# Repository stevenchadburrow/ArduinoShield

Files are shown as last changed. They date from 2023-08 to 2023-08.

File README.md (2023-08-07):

# ArduinoShield

This project is designed to make an Arduino into a standalone microcomputer.

Runs the Arduino Uno at the standard 16 MHz.  The shield gives the ATMega238 microcontroller up to 16KB of additional RAM. VGA output of 512x240 monochrome character display, allowing for 64-column text.  Also supports PS/2 Keyboard input and square wave audio output.

This uses the Xilinx XC9572XL CPLD, programmed using Xilinx ISE and 'xc3sprog'.

BASIC and a Roguelike Game were created for the system.

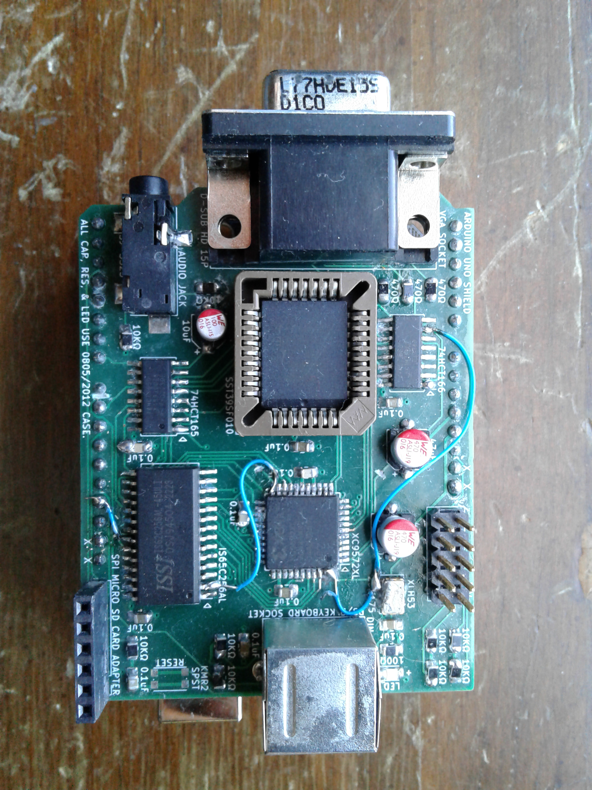
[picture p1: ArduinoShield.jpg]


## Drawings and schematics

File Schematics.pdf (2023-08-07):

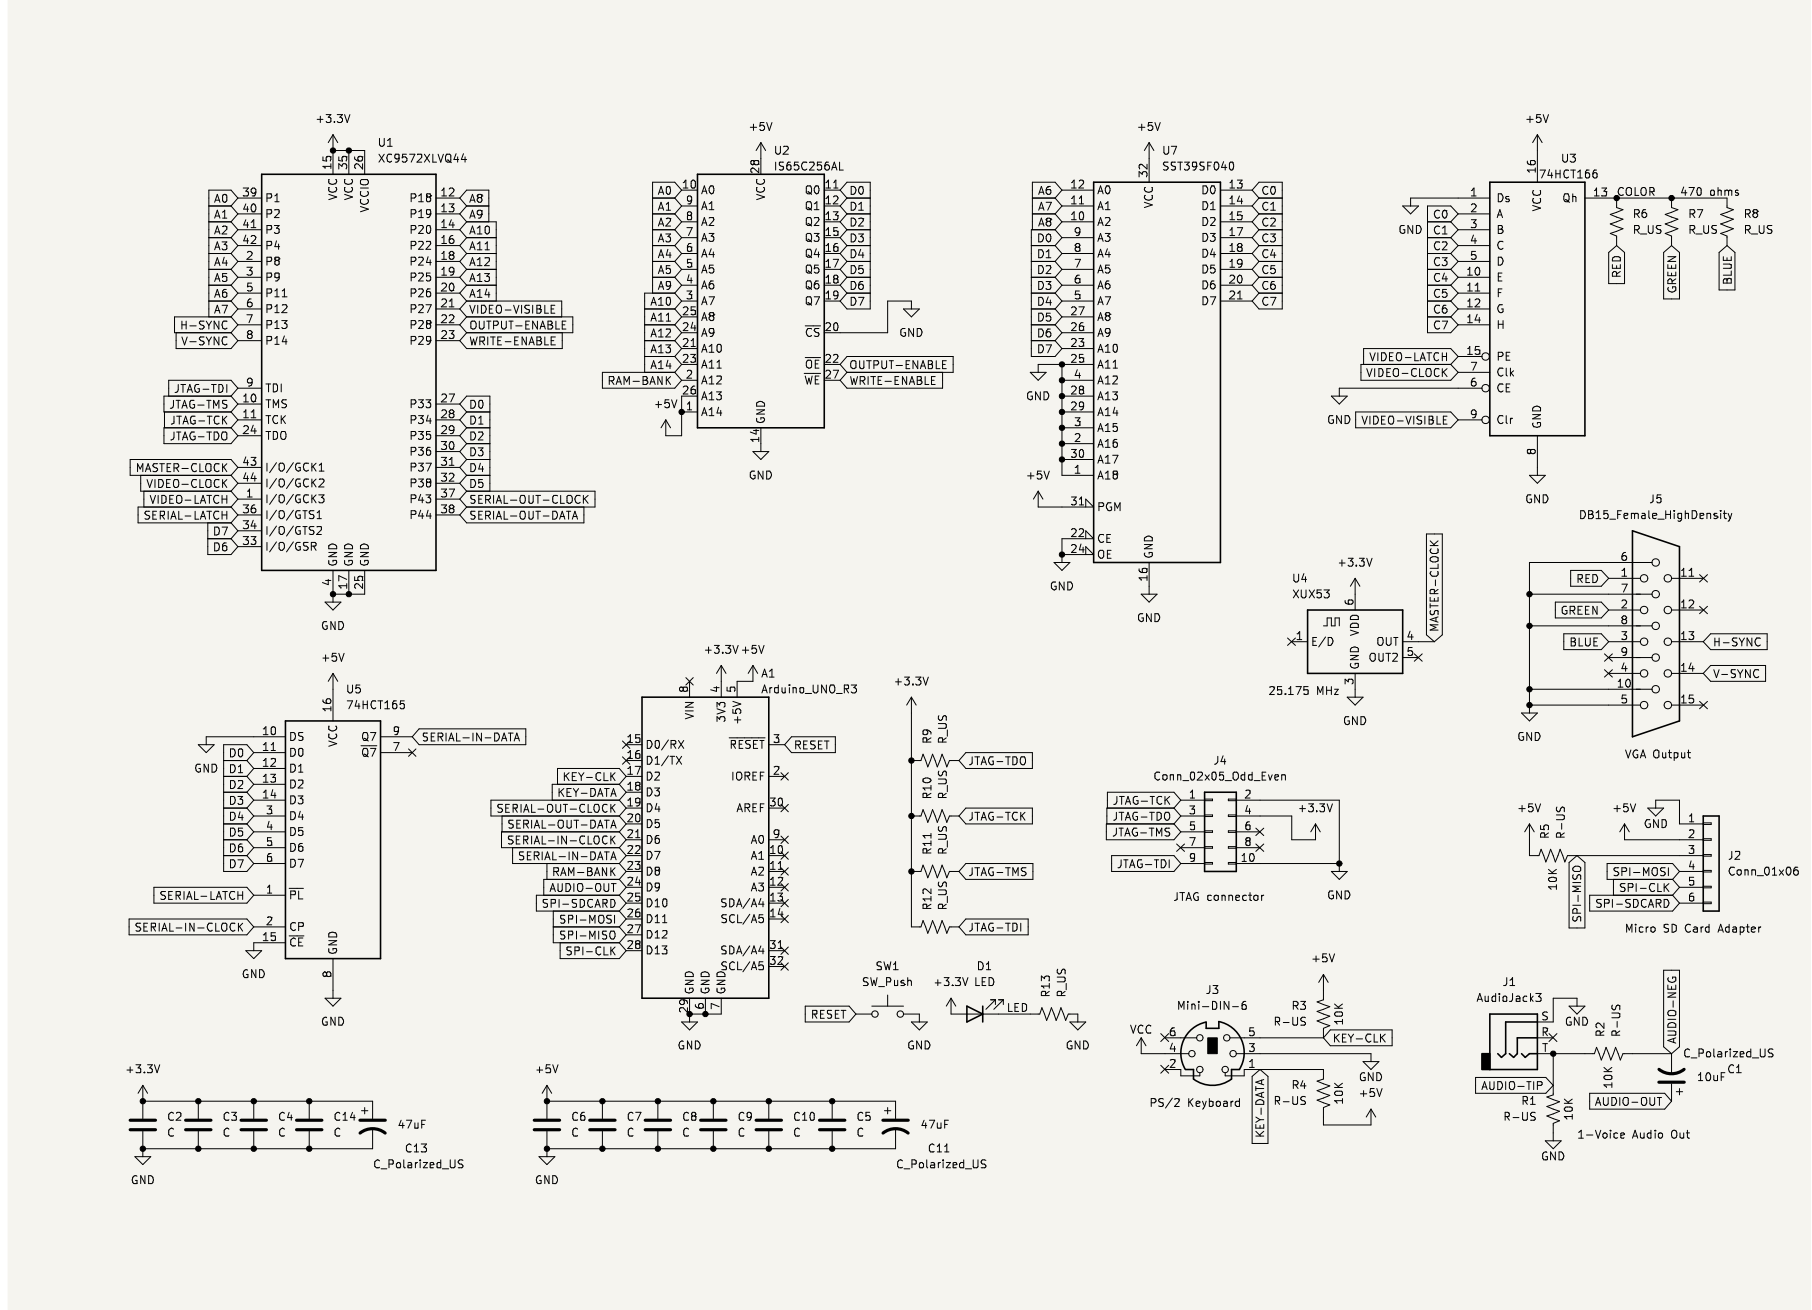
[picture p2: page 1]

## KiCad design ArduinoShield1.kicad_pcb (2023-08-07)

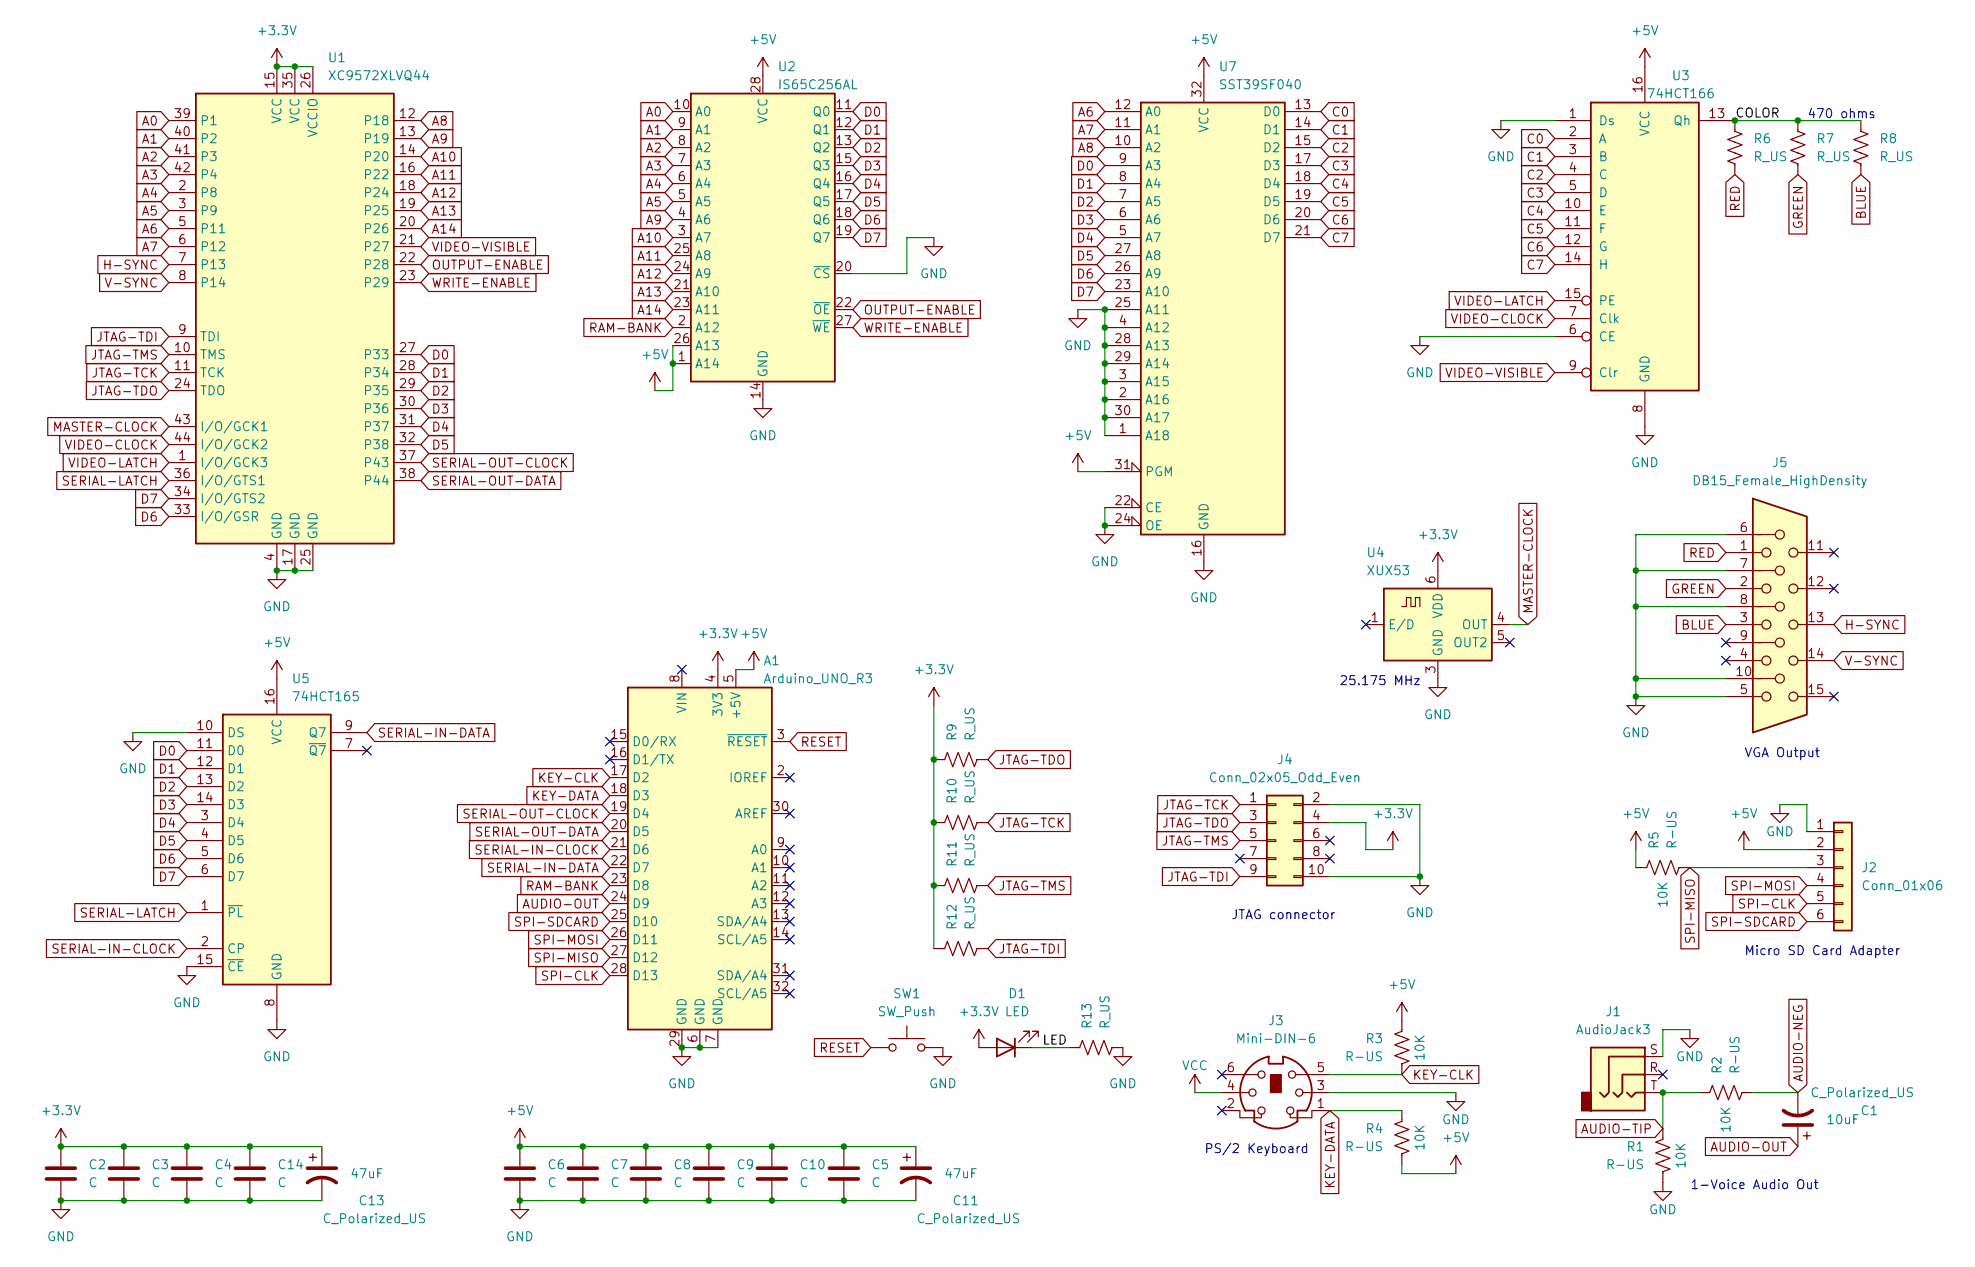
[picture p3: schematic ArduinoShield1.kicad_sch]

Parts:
A1: Arduino_UNO_R3
C1: C_Polarized_US; CP_Elec_4x5.4
C2, C3, C4, C5, C6, C7, C8, C9, C10, C14: C; C_0805_2012Metric_Pad1.18x1.45mm_HandSolder
C11, C13: C_Polarized_US; CP_Elec_5x5.4
D1: LED; LED_1206_3216Metric_Pad1.42x1.75mm_HandSolder
J1: AudioJack3; Jack_3.5mm_CUI_custom_SJ-3524-SMT_Horizontal
J2: Conn_01x06; PinSocket_custompin1_1x06_P2.54mm_Vertical
J3: Mini-DIN-6; PS2_Din6
J4: Conn_02x05_Odd_Even; PinHeader_2x05_P2.54mm_Vertical
J5: DB15_Female_HighDensity; DSUB-15-HD_Female_Horizontal_P2.29x2.54mm_VGA
R1, R2, R3, R4, R5: R-US; R_0805_2012Metric_Pad1.20x1.40mm_HandSolder
R6, R7, R8, R9, R10, R11, R12: R_US; R_0805_2012Metric_Pad1.20x1.40mm_HandSolder
R13: R_US; R_1206_3216Metric_Pad1.30x1.75mm_HandSolder
SW1: SW_Push; SW_Push_1P1T_NO_CK_KMR2
U1: XC9572XLVQ44; TQFP-44_10x10mm_P0.8mm
U2: IS65C256AL; SOIC-28W_custom_7.5x18.7mm_P1.27mm
U3: 74HCT166; SOIC-16_4.55x10.3mm_P1.27mm
U4: XUX53; Oscillator_SMD_IDT_JS6-6_5.0x3.2mm_P1.27mm
U5: 74HCT165; SOIC-16_4.55x10.3mm_P1.27mm
U7: SST39SF040; PLCC-32_THT-Socket

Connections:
+3.3V: A1.4 (3V3), C2.1, C3.1, C4.1, C13.1, C14.1, D1.2 (A), J4.4, R9.1, R10.1, R11.1, R12.1, U1.15 (VCC), U1.26 (VCCIO), U1.35 (VCC), U4.6 (VDD)
/COLOR: R6.1, R7.1, R8.1, U3.13 (Qh)
/LED: D1.1 (K), R13.1
A0: U1.39 (P1), U2.10 (A0)
A1: U1.40 (P2), U2.9 (A1)
A2: U1.41 (P3), U2.8 (A2)
A3: U1.42 (P4), U2.7 (A3)
A4: U1.2 (P8), U2.6 (A4)
A5: U1.3 (P9), U2.5 (A5)
A6: U1.5 (P11), U7.12 (A0)
A7: U1.6 (P12), U7.11 (A1)
A8: U1.12 (P18), U7.10 (A2)
A9: U1.13 (P19), U2.4 (A6)
A10: U1.14 (P20), U2.3 (A7)
A11: U1.16 (P22), U2.25 (A8)
A12: U1.18 (P24), U2.24 (A9)
A13: U1.19 (P25), U2.21 (A10)
A14: U1.20 (P26), U2.23 (A11)
AUDIO-NEG: C1.2, R2.2
AUDIO-OUT: A1.24 (D9), C1.1
AUDIO-TIP: J1.T, R1.1, R2.1
BLUE: J5.3, R8.2
C0: U3.2 (A), U7.13 (D0)
C1: U3.3 (B), U7.14 (D1)
C2: U3.4 (C), U7.15 (D2)
C3: U3.5 (D), U7.17 (D3)
C4: U3.10 (E), U7.18 (D4)
C5: U3.11 (F), U7.19 (D5)
C6: U3.12 (G), U7.20 (D6)
C7: U3.14 (H), U7.21 (D7)
D0: U1.27 (P33), U2.11 (Q0), U5.11 (D0), U7.9 (A3)
D1: U1.28 (P34), U2.12 (Q1), U5.12 (D1), U7.8 (A4)
D2: U1.29 (P35), U2.13 (Q2), U5.13 (D2), U7.7 (A5)
D3: U1.30 (P36), U2.15 (Q3), U5.14 (D3), U7.6 (A6)
D4: U1.31 (P37), U2.16 (Q4), U5.3 (D4), U7.5 (A7)
D5: U1.32 (P38), U2.17 (Q5), U5.4 (D5), U7.27 (A8)
D6: U1.33 (I/O/GSR), U2.18 (Q6), U5.5 (D6), U7.26 (A9)
D7: U1.34 (I/O/GTS2), U2.19 (Q7), U5.6 (D7), U7.23 (A10)
GND: A1.6 (GND), A1.7 (GND), A1.29 (GND), C2.2, C3.2, C4.2, C5.2, C6.2, C7.2, C8.2, C9.2, C10.2, C11.2, C13.2, C14.2, J1.S, J2.1, J3.3, J4.2, J4.10, J5.5, J5.6, J5.7, J5.8, J5.10, R1.2, R13.2, SW1.2, U1.4 (GND), U1.17 (GND), U1.25 (GND), U2.14 (GND), U2.20 (~CS), U3.1 (Ds), U3.6 (CE), U3.8 (GND), U4.3 (GND), U5.8 (GND), U5.10 (DS), U5.15 (~CE), U7.1 (A18), U7.2 (A16), U7.3 (A15), U7.4 (A12), U7.16 (GND), U7.22 (CE), U7.24 (OE), U7.25 (A11), U7.28 (A13), U7.29 (A14), U7.30 (A17)
GREEN: J5.2, R7.2
H-SYNC: J5.13, U1.7 (P13)
JTAG-TCK: J4.1, R10.2, U1.11 (TCK)
JTAG-TDI: J4.9, R12.2, U1.9 (TDI)
JTAG-TDO: J4.3, R9.2, U1.24 (TDO)
JTAG-TMS: J4.5, R11.2, U1.10 (TMS)
KEY-CLK: A1.17 (D2), J3.5, R3.2
KEY-DATA: A1.18 (D3), J3.1, R4.1
MASTER-CLOCK: U1.43 (I/O/GCK1), U4.4 (OUT)
OUTPUT-ENABLE: U1.22 (P28), U2.22 (~OE)
RAM-BANK: A1.23 (D8), U2.2 (A12)
RED: J5.1, R6.2
RESET: A1.3 (~RESET), SW1.1
SERIAL-IN-CLOCK: A1.21 (D6), U5.2 (CP)
SERIAL-IN-DATA: A1.22 (D7), U5.9 (Q7)
SERIAL-LATCH: U1.36 (I/O/GTS1), U5.1 (~PL)
SERIAL-OUT-CLOCK: A1.19 (D4), U1.37 (P43)
SERIAL-OUT-DATA: A1.20 (D5), U1.38 (P44)
SPI-CLK: A1.28 (D13), J2.5
SPI-MISO: A1.27 (D12), J2.3, R5.2
SPI-MOSI: A1.26 (D11), J2.4
SPI-SDCARD: A1.25 (D10), J2.6
V-SYNC: J5.14, U1.8 (P14)
VIDEO-CLOCK: U1.44 (I/O/GCK2), U3.7 (Clk)
VIDEO-LATCH: U1.1 (I/O/GCK3), U3.15 (PE)
VIDEO-VISIBLE: U1.21 (P27), U3.9 (Clr)
WRITE-ENABLE: U1.23 (P29), U2.27 (~WE)

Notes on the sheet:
PS/2 Keyboard
JTAG connector
1-Voice Audio Out
Micro SD Card Adapter
VGA Output
25.175 MHz
470 ohms

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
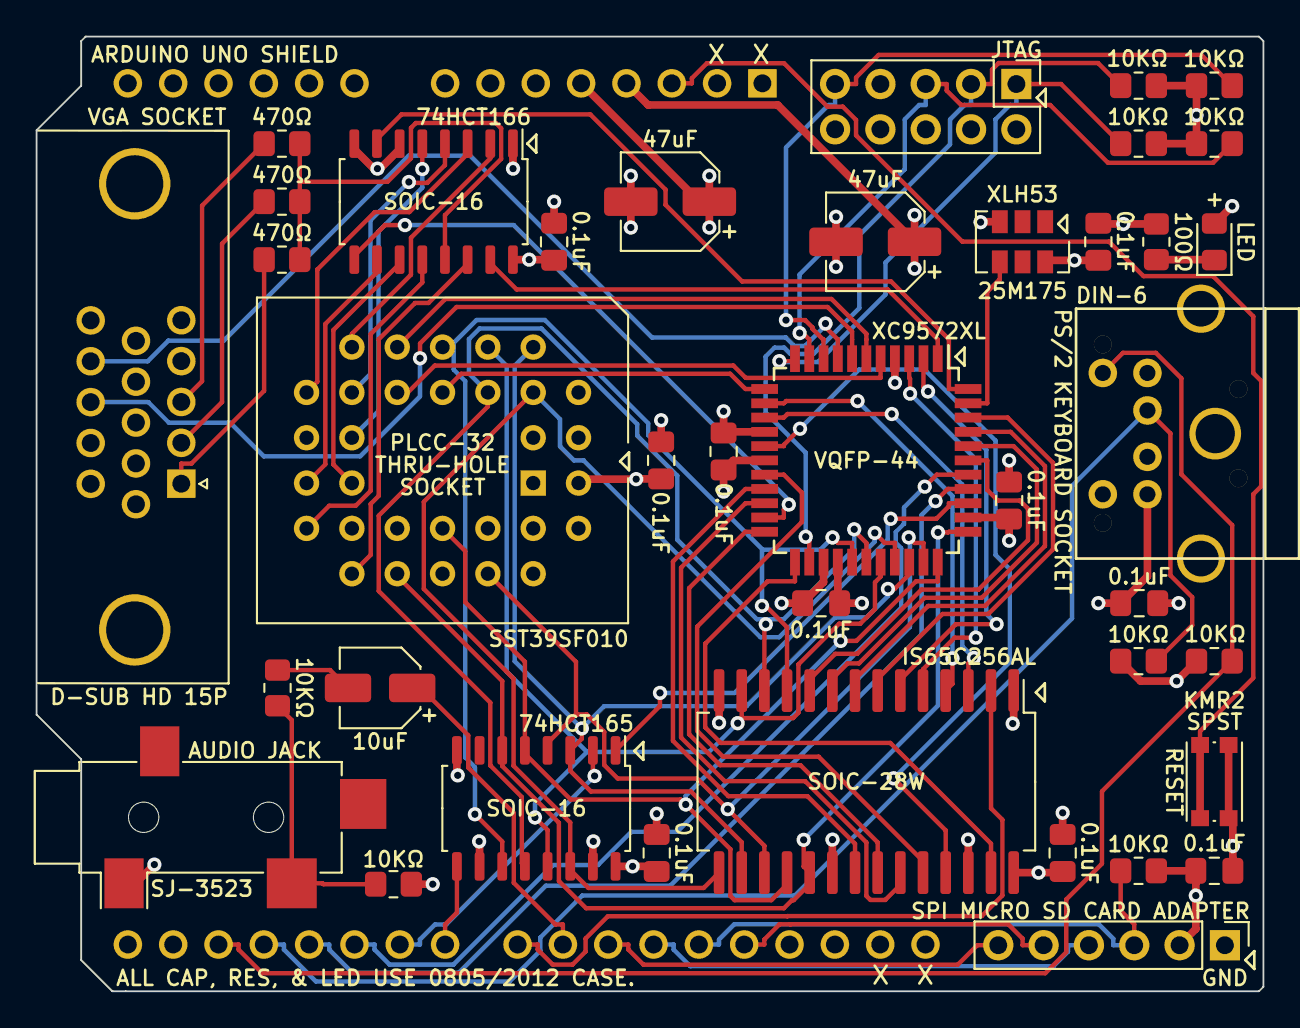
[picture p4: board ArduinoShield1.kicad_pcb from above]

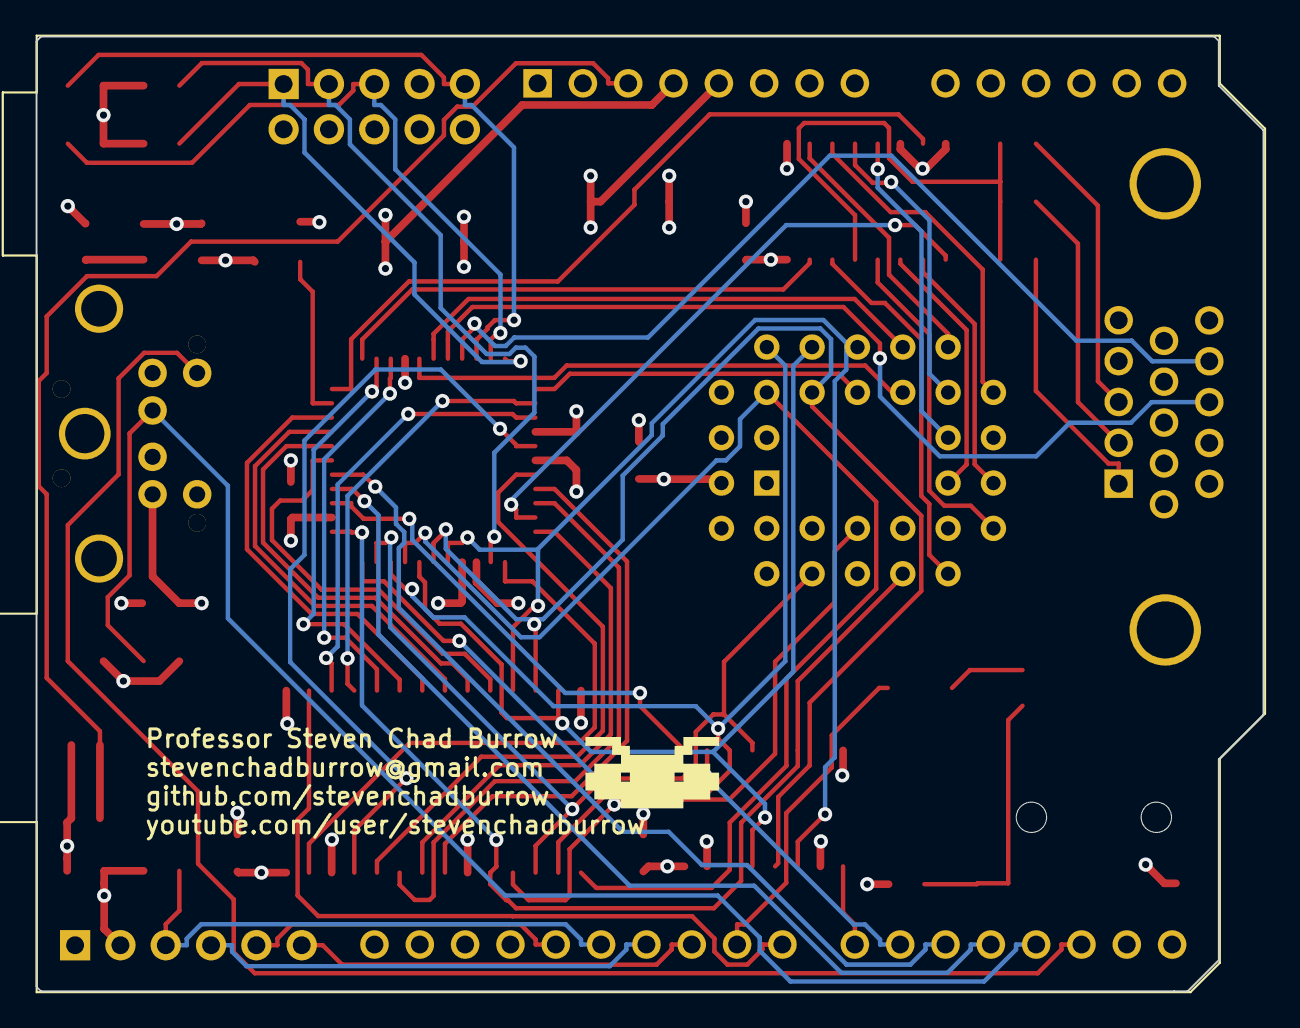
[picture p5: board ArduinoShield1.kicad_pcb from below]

Board: 4 copper layers, 68.8 x 53.5 mm, 41 parts (2 on the bottom side), 67 nets.

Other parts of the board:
G100: LOGO; Mystery

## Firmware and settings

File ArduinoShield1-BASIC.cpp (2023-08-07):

// This is written for the Arduino UNO
// To run this, you can either use the Arduino IDE AppImage,
// OR you can use 'arduino-cli'.
// Follow typical installation process for the 'arduino-cli'.
// The following bash script can be used to automatically program the Arduino UNO:

// echo "ArduinoProgrammer.sh <sketch_file>"
// x=${1%.*}
// y=${x##*/}
// /path/to/arduino-cli sketch new $x
// cp $1 $x/$y.ino
// /path/to/arduino-cli compile --fqbn arduino:avr:uno $x/$y.ino
// /path/to/arduino-cli upload -p /dev/ttyACM0 --fqbn arduino:avr:uno $x/$y.ino
// /path/to/arduino-cli monitor -p /dev/ttyACM0

// You can put that script into a .sh file to let it program automatically.
// No extra libraries should be needed to be installed here,
// the <EEPROM.h> library should be built in and does not need to be installed separately.


#include <EEPROM.h>

unsigned char shared_memory[512]; // duplicated in first 4K from $0000-$0FFF
unsigned char screen_memory[960]; // used for 40x24 and 64x15 fast vertical scrolling (and rogue variables too...)

const bool serial_debug = false; // change to stop error messages
const bool serial_output = true; // change to stop serial output
const bool serial_input = true; // change to stop serial input
unsigned char serial_last = 0x00;

int display_width = 40; // 40 or 64
int display_height = 24; // 24 or 15
int display_left = 12; // 12 or 0
int display_top = 1; // 1 or 5

const bool display_check = false; // double checks reads and writes
const int display_delay = 1; // microseconds

const int display_input_clock = 6;
const int display_input_data = 7;

const int display_output_clock = 4;
const int display_output_data = 5;

//const int display_ram_bank = 8; // not used anymore
//int display_ram_bank_value = 0;

void display_toggleinput()
{
	digitalWrite(display_input_clock, HIGH);
	digitalWrite(display_input_clock, LOW);
};

void display_toggleoutput()
{
	digitalWrite(display_output_clock, HIGH);
	digitalWrite(display_output_clock, LOW);
};

unsigned char display_receivebyte()
{
	unsigned char temp_value = 0x00;

	for (int i=0; i<8; i++)
	{
		temp_value = temp_value << 1;

		if (digitalRead(display_input_data) == HIGH)
		{
			temp_value += 0x01;
		}

		display_toggleinput();
	}
	
	return temp_value;
};

void display_sendbyte(const unsigned char value)
{
	unsigned char temp_value = value;

	for (int i=0; i<8; i++)
	{
		if (temp_value >= 0x80)
		{
			digitalWrite(display_output_data, HIGH);
		}
		else
		{
			digitalWrite(display_output_data, LOW);
		}

		temp_value = temp_value << 1;

		display_toggleoutput();
	}
};

unsigned char display_receivepacket(const unsigned char high, const unsigned char low) // double check each byte received
{
	if (display_check)
	{
		display_sendbyte((unsigned char)((high&0x3F)+0x80));
		display_sendbyte((unsigned char)(low));
		display_sendbyte((unsigned char)(0x00));
		delayMicroseconds(display_delay); // just in case
		display_toggleoutput();

		unsigned char temp_check[2];

		temp_check[1] = temp_check[0];

		temp_check[0] = display_receivebyte(); 

		do
		{
			display_sendbyte((unsigned char)((high&0x3F)+0x80));
			display_sendbyte((unsigned char)(low));
			display_sendbyte((unsigned char)(0x00));
			delayMicroseconds(display_delay); // just in case
			display_toggleoutput();
	
			temp_check[1] = temp_check[0];
	
			temp_check[0] = display_receivebyte();
	
			if (serial_debug)
			{
				if (temp_check[0] != temp_check[1])
				{
					unsigned char temp_binary;
	
					Serial.println("");
	
					Serial.print('R');
					Serial.print(' ');
					
					temp_binary = temp_check[0];
	
					for (int i=0; i<8; i++)
					{
						if (temp_binary >= 0x80) Serial.print('1');
						else Serial.print('0');
					
						temp_binary = temp_binary << 1;
		
						if (i == 3) Serial.print(' ');
					}
					
					Serial.println("");
	
					Serial.print(' ');
					Serial.print(' ');
	
					temp_binary = temp_check[1];
	
					for (int i=0; i<8; i++)
					{
						if (temp_binary >= 0x80) Serial.print('1');
						else Serial.print('0');
					
						temp_binary = temp_binary << 1;
	
						if (i == 3) Serial.print(' ');
					}
	
					Serial.println("");
				}
			}
		} 
		while (temp_check[0] != temp_check[1]);

		return temp_check[0];
	}
	else
	{
		display_sendbyte((unsigned char)((high&0x3F)+0x80));
		display_sendbyte((unsigned char)(low));
		display_sendbyte((unsigned char)(0x00));
		delayMicroseconds(display_delay); // just in case
		display_toggleoutput();	
	
		return display_receivebyte();
	}
};

void display_sendpacket(const unsigned char high, const unsigned char low, const unsigned char value) // only check bytes NOT sent to screen
{
	if (display_check)
	{
		unsigned char temp_check;

		do
		{
			display_sendbyte((unsigned char)((high&0x3F)+0xC0));
			display_sendbyte((unsigned char)(low));
			display_sendbyte((unsigned char)(value));
			delayMicroseconds(display_delay); // just in case
			display_toggleoutput();
	
			if ((unsigned char)(high&0x08) == 0x08)
			{
				display_sendbyte((unsigned char)((high&0x3F)+0x80));
				display_sendbyte((unsigned char)(low));
				display_sendbyte((unsigned char)(value));
				delayMicroseconds(display_delay); // just in case
				display_toggleoutput();
	
				temp_check = display_receivebyte();
			}
			else
			{
				temp_check = value;
			}
	
			if (serial_debug)
			{
				if (temp_check != value)
				{
					unsigned char temp_binary;
	
					Serial.println("");
	
					Serial.print('W');
					Serial.print(' ');
					
					temp_binary = temp_check;
	
					for (int i=0; i<8; i++)
					{
						if (temp_binary >= 0x80) Serial.print('1');
						else Serial.print('0');
					
						temp_binary = temp_binary << 1;
		
						if (i == 3) Serial.print(' ');
					}
					
					Serial.println("");
	
					Serial.print(' ');
					Serial.print(' ');
	
					temp_binary = value;
	
					for (int i=0; i<8; i++)
					{
						if (temp_binary >= 0x80) Serial.print('1');
						else Serial.print('0');
					
						temp_binary = temp_binary << 1;
	
						if (i == 3) Serial.print(' ');
					}
	
					Serial.println("");
				}
			}
		}
		while (temp_check != value);
	}
	else
	{
		display_sendbyte((unsigned char)((high&0x3F)+0xC0));
		display_sendbyte((unsigned char)(low));
		display_sendbyte((unsigned char)(value));
		delayMicroseconds(display_delay); // just in case
		display_toggleoutput();
	}
};

unsigned char display_receivecharacter(const unsigned char row, const unsigned char column)
{
	unsigned char low = (unsigned char)((unsigned char)(column & 0x3F) + (unsigned char)((row & 0x03) << 6));
	unsigned char high = (unsigned char)((row & 0xFC) >> 2);

	return display_receivepacket(high, low);
};

void display_sendcharacter(const unsigned char row, const unsigned char column, const unsigned char value)
{
	unsigned char low = (unsigned char)((unsigned char)(column & 0x3F) + (unsigned char)((row & 0x03) << 6));
	unsigned char high = (unsigned char)((row & 0xFC) >> 2);

	display_sendpacket(high, low, value);
};

void display_initialize()
{
	pinMode(display_output_clock, OUTPUT);
	pinMode(display_output_data, OUTPUT);

	digitalWrite(display_output_clock, LOW);
	digitalWrite(display_output_data, LOW);

	pinMode(display_input_clock, OUTPUT);
	pinMode(display_input_data, INPUT);

	digitalWrite(display_input_clock, LOW);

	for (int i=0; i<32; i++)
	{
		display_toggleoutput(); // clears shift register
	}
};

void display_clearmemory()
{	
	for (int i=0; i<16384; i++)
	{
		display_sendpacket((unsigned char)(i/256), (unsigned char)(i%256), 0x00);
	}
};


void string_copy(const char *A, char *B)
{
	for (int i=0; i<256; i++)
	{
		if (A[i] == 0 || A[i] == '\n') break;
		else B[i] = A[i];
	}
};

void string_print(int Y, int X, const char *A)
{
	for (int i=0; i<256; i++)
	{
		if (A[i] == 0 || A[i] == '\n') break;
		else
		{
			display_sendcharacter(Y, X, A[i]);

			X++;

			if (serial_output)
			{
				Serial.print((char)A[i]);
				delay(1);
			}
		}
	}

	if (serial_output)
	{
		Serial.println("");
		delay(1);
	}
};


const int keyboard_clock = 2;
const int keyboard_data = 3;

volatile unsigned char keyboard_bit = 0x00;
volatile unsigned char keyboard_byte = 0x00;
volatile unsigned char keyboard_counter = 0x00;
volatile unsigned char keyboard_buffer[16];
volatile unsigned char keyboard_read_pos = 0x00;
volatile unsigned char keyboard_write_pos = 0x00;
unsigned char keyboard_extended = 0x00;
unsigned char keyboard_release = 0x00;
unsigned char keyboard_shift = 0x00;
unsigned char keyboard_capslock = 0x00;
unsigned char keyboard_mode = 0x00;
unsigned char keyboard_serial = 0x00;

unsigned char keyboard_pos_x = 0x00;
unsigned char keyboard_pos_y = 0x00;
unsigned char keyboard_invert = 0x80; // 0x00 or 0x80

const unsigned char keyboard_text[128] PROGMEM = 
"\\ for Editor, and to Break. Commands:\nHELP, QUIT, CLEAR, ALIGN, INVERT,\nLOAD, SAVE, NEW, DIR, RUN, and MON\" \" _";

const unsigned char keyboard_conversion[256] PROGMEM = {
	 0x00,0x16,0x0C,0x0F,0x1E,0x1C,0x1D,0x15,
	 0x00,0x18,0x07,0x0E,0x1F,0x09,0x60,0x00,
	 0x00,0x00,0x00,0x00,0x00,0x71,0x31,0x00,
	 0x00,0x00,0x7A,0x73,0x61,0x77,0x32,0x00,
	 0x00,0x63,0x78,0x64,0x65,0x34,0x33,0x00,
	 0x00,0x20,0x76,0x66,0x74,0x72,0x35,0x00,
	 0x00,0x6E,0x62,0x68,0x67,0x79,0x36,0x00,
	 0x00,0x00,0x6D,0x6A,0x75,0x37,0x38,0x00,
	 0x00,0x2C,0x6B,0x69,0x6F,0x30,0x39,0x00,
	 0x00,0x2E,0x2F,0x6C,0x3B,0x70,0x2D,0x00,
	 0x00,0x00,0x27,0x00,0x5B,0x3D,0x00,0x00,
	 0x00,0x00,0x0D,0x5D,0x00,0x5C,0x00,0x00,
	 0x00,0x00,0x00,0x00,0x00,0x00,0x08,0x00,
	 0x00,0x31,0x00,0x34,0x37,0x00,0x00,0x00,
	 0x30,0x2E,0x32,0x35,0x36,0x38,0x1B,0x00,
	 0x19,0x2B,0x33,0x2D,0x2A,0x39,0x00,0x00,

	 0x00,0x16,0x0C,0x0F,0x1E,0x1C,0x1D,0x15,
	 0x00,0x18,0x07,0x0E,0x1F,0x09,0x7E,0x00,
	 0x00,0x00,0x00,0x00,0x00,0x51,0x21,0x00,
	 0x00,0x00,0x5A,0x53,0x41,0x57,0x40,0x00,
	 0x00,0x43,0x58,0x44,0x45,0x24,0x23,0x00,
	 0x00,0x20,0x56,0x46,0x54,0x52,0x25,0x00,
	 0x00,0x4E,0x42,0x48,0x47,0x59,0x5E,0x00,
	 0x00,0x00,0x4D,0x4A,0x55,0x26,0x2A,0x00,
	 0x00,0x3C,0x4B,0x49,0x4F,0x29,0x28,0x00,
	 0x00,0x3E,0x3F,0x4C,0x3A,0x50,0x5F,0x00,
	 0x00,0x00,0x22,0x00,0x7B,0x2B,0x00,0x00,
	 0x00,0x00,0x0D,0x7D,0x00,0x7C,0x00,0x00,
	 0x00,0x00,0x00,0x00,0x00,0x00,0x08,0x00,
	 0x00,0x03,0x00,0x13,0x02,0x00,0x00,0x00,
	 0x1A,0x7F,0x12,0x35,0x14,0x11,0x1B,0x00,
	 0x19,0x2B,0x04,0x2D,0x2A,0x01,0x00,0x00
};

void keyboard_interrupt()
{
	keyboard_bit = digitalRead(keyboard_data);
	
	keyboard_byte = keyboard_byte >> 1;

	if (keyboard_bit == HIGH) keyboard_byte += 0x80;

	keyboard_counter++;

	if (keyboard_counter == 0x09)
	{
		keyboard_buffer[keyboard_write_pos] = keyboard_byte;
		keyboard_write_pos++;
		if (keyboard_write_pos >= 0x10) keyboard_write_pos = 0x00;
	}
	else if (keyboard_counter == 0x0B)
	{
		keyboard_counter = 0x00;
	}

	while (digitalRead(keyboard_clock) == LOW) {}

	return;
};

void keyboard_initialize()
{
	pinMode(keyboard_clock, INPUT_PULLUP);
	pinMode(keyboard_data, INPUT_PULLUP);

	attachInterrupt(digitalPinToInterrupt(keyboard_clock), keyboard_interrupt, LOW);

	interrupts(); // just in case
};

void keyboard_clearscreen()
{
	keyboard_pos_x = 0x00;
	keyboard_pos_y = 0x00;

	for (int i=0; i<2048; i++)
	{
		display_sendpacket(keyboard_pos_y, keyboard_pos_x, 0x00);

		keyboard_pos_x++;

		if (keyboard_pos_x == 0x00) keyboard_pos_y++;
	}
	
	for (int i=0; i<display_height; i++)
	{
		for (int j=0; j<display_width; j++)
		{
			screen_memory[i*display_width+j] = 0x00;
		}
	}

	for (int i=display_top; i<display_height+display_top+4; i++)
	{
		for (int j=display_left; j<display_width+display_left; j++)
		{
			display_sendcharacter(i, j, keyboard_invert);
		}
	}

	keyboard_pos_x = (unsigned char)display_left;
	keyboard_pos_y = (unsigned char)display_top;
};

void keyboard_menu()
{
	for (int i=0; i<display_width; i++)
	{
		display_sendcharacter((unsigned char)(display_height+display_top), (unsigned char)(i+display_left), (unsigned char)('_'+keyboard_invert));
	}

	char temp_char, temp_mode;

	keyboard_pos_x = (unsigned char)display_left;
	keyboard_pos_y = (unsigned char)(display_height+display_top) + 1;

	temp_mode = keyboard_mode;

	keyboard_mode = 0x00;

	for (int i=0; i<128; i++)
	{
		temp_char = (char)pgm_read_byte_near(keyboard_text + (unsigned char)(i));

		if (temp_char == '_') break;

		if (temp_char == '\n')
		{
			temp_char = 0x00; 

			display_sendcharacter(keyboard_pos_y, keyboard_pos_x, (unsigned char)(' '+keyboard_invert));

			keyboard_pos_x = (unsigned char)display_left;
			keyboard_pos_y += 1;

			if (serial_output)
			{
				Serial.println("");
			}
		}
		else
		{
			keyboard_print(temp_char);
		}
	}

	display_sendcharacter(keyboard_pos_y, keyboard_pos_x, (unsigned char)(' '+keyboard_invert));

	if (serial_output)
	{
		Serial.println("");
	}

	keyboard_mode = temp_mode;

	audio_note(2000); // just a beep

	keyboard_pos_x = (unsigned char)display_left;
	keyboard_pos_y = (unsigned char)display_top;
	display_sendcharacter(keyboard_pos_y, keyboard_pos_x, (unsigned char)(screen_memory[(keyboard_pos_y-display_top)*display_width+keyboard_pos_x-display_left]+0x80+keyboard_invert)); // cursor
};

void keyboard_verticalscroll()
{
	for (int i=0; i<display_height; i++)
	{
		for (int j=0; j<display_width; j++)
		{
			screen_memory[i*display_width+j] = screen_memory[(i+1)*display_width+j];
		}
	}
		
	for (int j=0; j<display_width; j++)
	{
		screen_memory[(display_height-1)*display_width+j] = 0x00;
	}

	for (int i=0; i<display_height; i++)
	{
		for (int j=0; j<display_width; j++)
		{
			display_sendcharacter(i+display_top, j+display_left, screen_memory[i*display_width+j]+keyboard_invert);
		}
	}

	return;
};

unsigned char keyboard_character()
{
	unsigned char temp_value = 0x00;
	unsigned char temp_second = 0x00;

	if (keyboard_read_pos != keyboard_write_pos)
	{
		temp_value = keyboard_buffer[keyboard_read_pos];

		if (temp_value == 0xF0) // release
		{
			keyboard_release = 0xF0;
		}
		else if (temp_value == 0xE0) // extended
		{
			keyboard_extended = 0xE0;
		}
		else
		{
			if (keyboard_release > 0x00)
			{
				if (temp_value == 0x12 || temp_value == 0x59) keyboard_shift = 0x00;
			}
			else
			{
				if (temp_value == 0x58) keyboard_capslock += 0x80;
				else if (temp_value == 0x12 || temp_value == 0x59) keyboard_shift = 0xFF;

				if (keyboard_capslock != 0x00) temp_value += 0x80;

				if (keyboard_shift == 0xFF) temp_value += 0x80;

				if (keyboard_extended > 0x00)
				{
					if (temp_value == 0x4A || temp_value == 0xCA) temp_value += 0x80; // numpad slash
					
					temp_second = (unsigned char)pgm_read_byte_near(keyboard_conversion + (unsigned char)(temp_value+0x80));
				}
				else
				{
					temp_second = (unsigned char)pgm_read_byte_near(keyboard_conversion + (unsigned char)(temp_value+0x00));
				}
			}

			keyboard_release = 0x00;
			keyboard_extended = 0x00;
		}

		keyboard_read_pos++;
		if (keyboard_read_pos >= 0x10) keyboard_read_pos = 0x00;

		return temp_second;
	}
	else
	{
		if (serial_input)
		{
			if (Serial.available() > 0)
			{
				if (serial_last == 0x10) // special serial key
				{
					serial_last = Serial.read();
				}
				else
				{
					serial_last = 0x10;
				}

				delay(1);

				return (unsigned char)serial_last;					
			}
			else
			{
				if (serial_last == 0x10)
				{
					serial_last = 0x0D;
				}
				else if (serial_last == 0x0D)
				{
					serial_last = 0x00;
				}
				else if (serial_last != 0x00)
				{
					serial_last = 0x10;
				}

				delay(1);

				return serial_last;
			}
		}
	
		return 0x00;
	}
};

void keyboard_print(unsigned char value)
{
	unsigned char temp_value = 0x00;
	unsigned char temp_x = 0x00;
	unsigned char temp_y = 0x00;

	if (value == 0x00) return;
	else if (value == 0x10) // special serial key
	{
		keyboard_serial = 0x01;
	}
	else if (value == 0x1C) // F1
	{

	}
	else if (value == 0x1D) // F2
	{
		
	}
	else if (value == 0x1E) // F3
	{
	
	}
	else if (value == 0x1F) // F4
	{

	}
	else if (value == 0x1A) // insert
	{

	}
	else if (value == 0x7F) // delete
	{

	}
	else if (value == 0x01) // page up
	{

	}
	else if (value == 0x02) // home
	{

	}
	else if (value == 0x03) // end
	{

	}
	else if (value == 0x04) // page down
	{

	}
	else if (value == 0x0D || value == 0x8D) // carriage return
	{
		display_sendcharacter(keyboard_pos_y, keyboard_pos_x, (unsigned char)(screen_memory[(keyboard_pos_y-display_top)*display_width+keyboard_pos_x-display_left]+keyboard_invert+0x00));

		keyboard_pos_x = (unsigned char)display_left;
		if (keyboard_pos_y < (unsigned char)(display_height+display_top)-1) keyboard_pos_y++;
		else
		{
			keyboard_verticalscroll();
	
			keyboard_pos_y = (unsigned char)(display_height+display_top)-1;
		}

		display_sendcharacter(keyboard_pos_y, keyboard_pos_x, (unsigned char)(screen_memory[(keyboard_pos_y-display_top)*display_width+keyboard_pos_x-display_left]+keyboard_invert+0x80));

		if (serial_output)
		{
			if (keyboard_serial == 0x00)
			{
				Serial.println("");
				delay(1);
			}
		}
	}
	else if (value == 0x11 || value == 0x91) // up arrow
	{
		if (keyboard_mode == 0x00)
		{
			display_sendcharacter(keyboard_pos_y, keyboard_pos_x, (unsigned char)(screen_memory[(keyboard_pos_y-display_top)*display_width+keyboard_pos_x-display_left]+keyboard_invert+0x00));
	
			if (keyboard_pos_y > (unsigned char)display_top) keyboard_pos_y--;
	
			display_sendcharacter(keyboard_pos_y, keyboard_pos_x, (unsigned char)(screen_memory[(keyboard_pos_y-display_top)*display_width+keyboard_pos_x-display_left]+keyboard_invert+0x80));
		}
	}
	else if (value == 0x12 || value == 0x92) // down arrow
	{
		if (keyboard_mode == 0x00)
		{
			display_sendcharacter(keyboard_pos_y, keyboard_pos_x, (unsigned char)(screen_memory[(keyboard_pos_y-display_top)*display_width+keyboard_pos_x-display_left]+keyboard_invert+0x00));
	
			if (keyboard_pos_y < (unsigned char)(display_height+display_top)-1) keyboard_pos_y++;
	
			display_sendcharacter(keyboard_pos_y, keyboard_pos_x, (unsigned char)(screen_memory[(keyboard_pos_y-display_top)*display_width+keyboard_pos_x-display_left]+keyboard_invert+0x80));
		}
	}
	else if (value == 0x08 || value == 0x13 || value == 0x88 || value == 0x93) // backspace or left arrow
	{
		if (keyboard_mode == 0x00 || value == 0x08 || value == 0x88)
		{
			display_sendcharacter(keyboard_pos_y, keyboard_pos_x, (unsigned char)(screen_memory[(keyboard_pos_y-display_top)*display_width+keyboard_pos_x-display_left]+keyboard_invert+0x00));

			if (keyboard_pos_x > (unsigned char)display_left) keyboard_pos_x--;

			display_sendcharacter(keyboard_pos_y, keyboard_pos_x, (unsigned char)(screen_memory[(keyboard_pos_y-display_top)*display_width+keyboard_pos_x-display_left]+keyboard_invert+0x80));
		}
	}
	else if (value == 0x09 || value == 0x14 || value == 0x89 || value == 0x94) // tab or right arrow
	{
		if (keyboard_mode == 0x00 || value == 0x09 || value == 0x89)
		{
			display_sendcharacter(keyboard_pos_y, keyboard_pos_x, (unsigned char)(screen_memory[(keyboard_pos_y-display_top)*display_width+keyboard_pos_x-display_left]+keyboard_invert+0x00));

			if (keyboard_pos_x < (unsigned char)(display_width+display_left-1)) keyboard_pos_x++;

			display_sendcharacter(keyboard_pos_y, keyboard_pos_x, (unsigned char)(screen_memory[(keyboard_pos_y-display_top)*display_width+keyboard_pos_x-display_left]+keyboard_invert+0x80));
		}
	}
	else if (value == 0x1B || value == 0x9B) // escape
	{
		if (keyboard_mode == 0x00)
		{
			keyboard_clearscreen();

			keyboard_menu();
	
			if (serial_output)
			{
				if (keyboard_serial == 0x00)
				{
					Serial.println("");
					delay(1);
				}
			}
		}
	}
	else
	{
		if (keyboard_mode != 0x00)
		{
			if (value > 0x60 && value <= 0x7A) value = (unsigned char)(value - 0x20); // upper case only
		}

		display_sendcharacter(keyboard_pos_y, keyboard_pos_x, (unsigned char)(value+keyboard_invert));
		screen_memory[(keyboard_pos_y-display_top)*display_width+keyboard_pos_x-display_left] = (unsigned char)value;

		if (keyboard_pos_x < (unsigned char)display_width+display_left-1) keyboard_pos_x++;
		else
		{
			keyboard_pos_x = (unsigned char)display_left;
			if (keyboard_pos_y < (unsigned char)(display_height+display_top)-1) keyboard_pos_y++;
			else
			{
				keyboard_verticalscroll();
				keyboard_pos_y = (unsigned char)(display_height+display_top)-1;
			}
		}

		display_sendcharacter(keyboard_pos_y, keyboard_pos_x, (unsigned char)(screen_memory[(keyboard_pos_y-display_top)*display_width+keyboard_pos_x-display_left]+keyboard_invert+0x80));

		if (serial_output)
		{
			if (keyboard_serial == 0x00)
			{
				Serial.print((char)value);
				delay(1);
			}
		}
	}
	
	if (value != 0x10) // special serial key
	{
		keyboard_serial = 0x00;
	}
};


const int sdcard_ss = 10;
const int sdcard_mosi = 11;
const int sdcard_miso = 12;
const int sdcard_sclk = 13;

void sdcard_enable()
{
	digitalWrite(sdcard_ss, LOW);
};

void sdcard_disable()
{
	digitalWrite(sdcard_ss, HIGH);
};

void sdcard_toggle()
{
	digitalWrite(sdcard_sclk, HIGH);
	digitalWrite(sdcard_sclk, LOW);
}

void sdcard_longdelay()
{
	delay(10);
};

void sdcard_sendbyte(unsigned char value)
{
	unsigned char temp_value = value;

	for (int i=0; i<8; i++)
	{
		if (temp_value >= 0x80)
		{
			digitalWrite(sdcard_mosi, HIGH);
		}
		else
		{
			digitalWrite(sdcard_mosi, LOW);
		}

		temp_value = temp_value << 1;

		sdcard_toggle();
	}
};

unsigned char sdcard_receivebyte()
{
	unsigned char temp_value = 0x00;

	for (int i=0; i<8; i++)
	{
		temp_value = temp_value << 1;

		if (digitalRead(sdcard_miso) == HIGH)
		{
			temp_value += 0x01;
		}

		sdcard_toggle();
	}

	return temp_value;
};
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
void loop()
{
	// put your main code here, to run repeatedly:

	if (loop_key == '\\') // editor
	{
		while (keyboard_character()) {}

		for (int i=0; i<command_size; i++) command_string[i] = 0x00;

		loop_key = editor_loop();
	}
	else
	{
		loop_key = keyboard_character();

		if (loop_key != '\\')
		{
			keyboard_print(loop_key); // scratchpad mode
		}
	}	
}

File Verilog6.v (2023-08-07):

`timescale 1ns / 1ps
//////////////////////////////////////////////////////////////////////////////////
// Company: 
// Engineer: 
// 
// Create Date:    05:32:52 07/17/2023 
// Design Name: 
// Module Name:    Verilog6 
// Project Name: 
// Target Devices: 
// Tool versions: 
// Description: 
//
// Dependencies: 
//
// Revision: 
// Revision 0.01 - File Created
// Additional Comments: 
//
//////////////////////////////////////////////////////////////////////////////////

// This is experimenting with doubling the RAM to 16KB.
module Verilog6(
	input master_clock, // 25.175 MHz
	output video_latch, // latches video shift register
	output video_visible,
	output write_enable, // controls RAM /WE signal
	output [15:0] address, // connects to RAM and ROM addresses
	output high_addr,
	output [7:0] data, // connects to RAM and ROM
	output reg hsync, // connected to VGA
	output reg vsync, // connected to VGA
	input serial_clock, // clock signal for input shift register
	input serial_data, // data from the input shift register
	output serial_latch // latches data from RAM into output shift register
);

reg half_clock; // 12.58 MHz
reg quarter_clock; // 6.29 MHz
reg eighth_clock; // 3.14 MHz
reg [16:0] video_addr;
reg hblank;
reg vblank;
reg [23:0] shift_value;
reg shift_ready;
reg shift_clear; 


//assign high_addr = (eighth_clock && shift_ready) ? shift_value[21] : 1'b0;
assign high_addr = 1'bz;

assign address[5:0] = (eighth_clock && shift_ready) ? shift_value[13:8] : video_addr[5:0];
assign address[8:6] = (eighth_clock && shift_ready) ? 3'b000 : video_addr[10:8];
assign address[15:9] = (eighth_clock && shift_ready) ? shift_value[20:14] : video_addr[16:11];
assign data[7:0] = (eighth_clock && shift_ready && shift_value[22]) ? shift_value[7:0] : 8'bzzzzzzzz;
assign write_enable = (/*~half_clock && */quarter_clock && eighth_clock && shift_ready && shift_value[22]) ? 1'b0 : 1'b1;
assign video_latch = (half_clock && quarter_clock && ~eighth_clock) ? 1'b0 : 1'b1;
assign video_visible = (hblank && vblank) ? 1'b1 : 1'b0;
assign serial_latch = (/*~half_clock && */quarter_clock && eighth_clock && shift_ready && ~shift_value[22]) ? 1'b0 : 1'b1;


always @(posedge master_clock) begin
	if (half_clock) begin
		if (quarter_clock) begin
			if (eighth_clock) begin

				if (shift_ready) begin
					shift_ready <= 1'b0;
					shift_clear <= 1'b1;
				end
					
				if (shift_value[23]) begin
					if (~shift_clear) begin
						shift_ready <= 1'b1;
					end
				end
				else begin
					shift_clear <= 1'b0;
				end
				
				if (video_addr[6:0] == 7'b1100010) begin
					if (video_addr[7]) begin
						if (video_addr[16:8] == 9'b100000110) begin
							video_addr[16:8] <= 9'b000000000;
						end
						else begin
							video_addr[16:8] <= video_addr[16:8] + 1;
						end
					end
						
					video_addr[7] <= ~video_addr[7];
					
					video_addr[6:0] <= 7'b000000;						
				end
				else begin
					video_addr[6:0] <= video_addr[6:0] + 1;
				end
			end
			else begin
				if (video_addr[6:0] == 7'b1000000) begin
					hblank <= 1'b0;
				end
				
				if (video_addr[6:0] == 7'b1001010) begin // 7'b1010000
					hsync <= 1'b0;
				end
					
				if (video_addr[6:0] == 7'b1010110) begin // 7'b1011100
					hsync <= 1'b1;
				end
				
				if (video_addr[6:0] == 7'b0000000) begin
					hblank <= 1'b1;
				end
				
				if (video_addr[6:0] == 7'b1100010) begin
					if (video_addr[7]) begin
						if (video_addr[16:8] == 9'b011101111) begin
							vblank <= 1'b0;
						end
						
						if (video_addr[16:8] == 9'b011110101) begin
							vsync <= 1'b0;
						end
						
						if (video_addr[16:8] == 9'b011110110) begin
							vsync <= 1'b1;
						end
						
						if (video_addr[16:8] == 9'b100000110) begin
							vblank <= 1'b1;
						end
					end
				end
			end
			
			eighth_clock <= ~eighth_clock;
		end
		
		quarter_clock <= ~quarter_clock;
	end
	
	half_clock <= ~half_clock;

end

always @(posedge serial_clock) begin
	
	if (shift_value[23] && shift_clear) begin
		shift_value[23:0] <= 24'b000000000000000000000000;
	end
	else begin
		shift_value[23:1] <= shift_value[22:0];
		
		shift_value[0] <= serial_data;
	end
end

endmodule
